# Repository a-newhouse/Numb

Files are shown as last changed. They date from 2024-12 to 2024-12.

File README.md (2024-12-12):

# Disclaimer
This is my first attempt, with [Duality](https://github.com/a-newhouse/Duality), to make a fully functional keyboard from A to Z. 
# Schematic
To start with, I knew I wanted to use an RP2040 and per key LEDs. So I searched how to make an RP2040 board amd i found a book made by Raberry PI called the [Hardware design with RP2040: Using RP2040 microcontrollers to build boards and products](./Schematic_&_PCB/Hardware_Design_RP2040.pdf). This book contains alot of information on how to make a RP2040 development board.
# PCB
# 3D modeling
# BOM
# Assembly
# QMK Firmware

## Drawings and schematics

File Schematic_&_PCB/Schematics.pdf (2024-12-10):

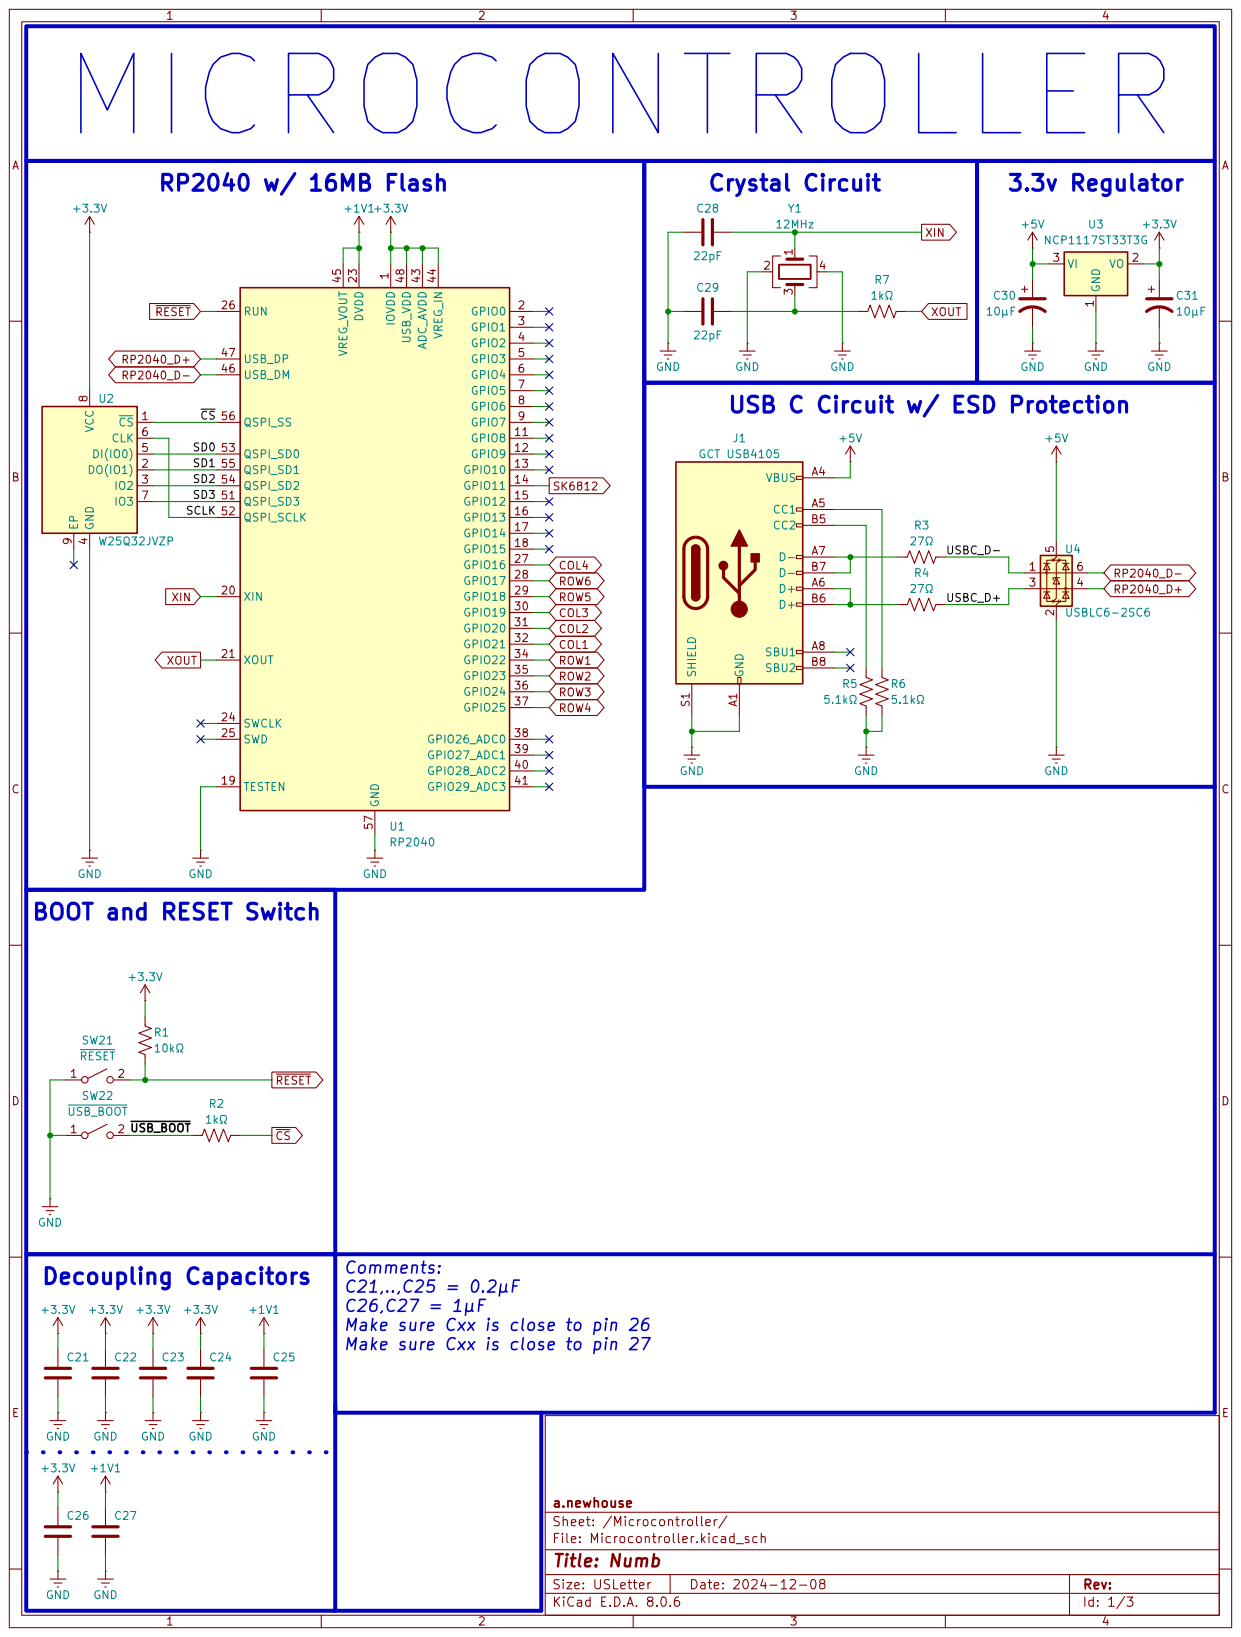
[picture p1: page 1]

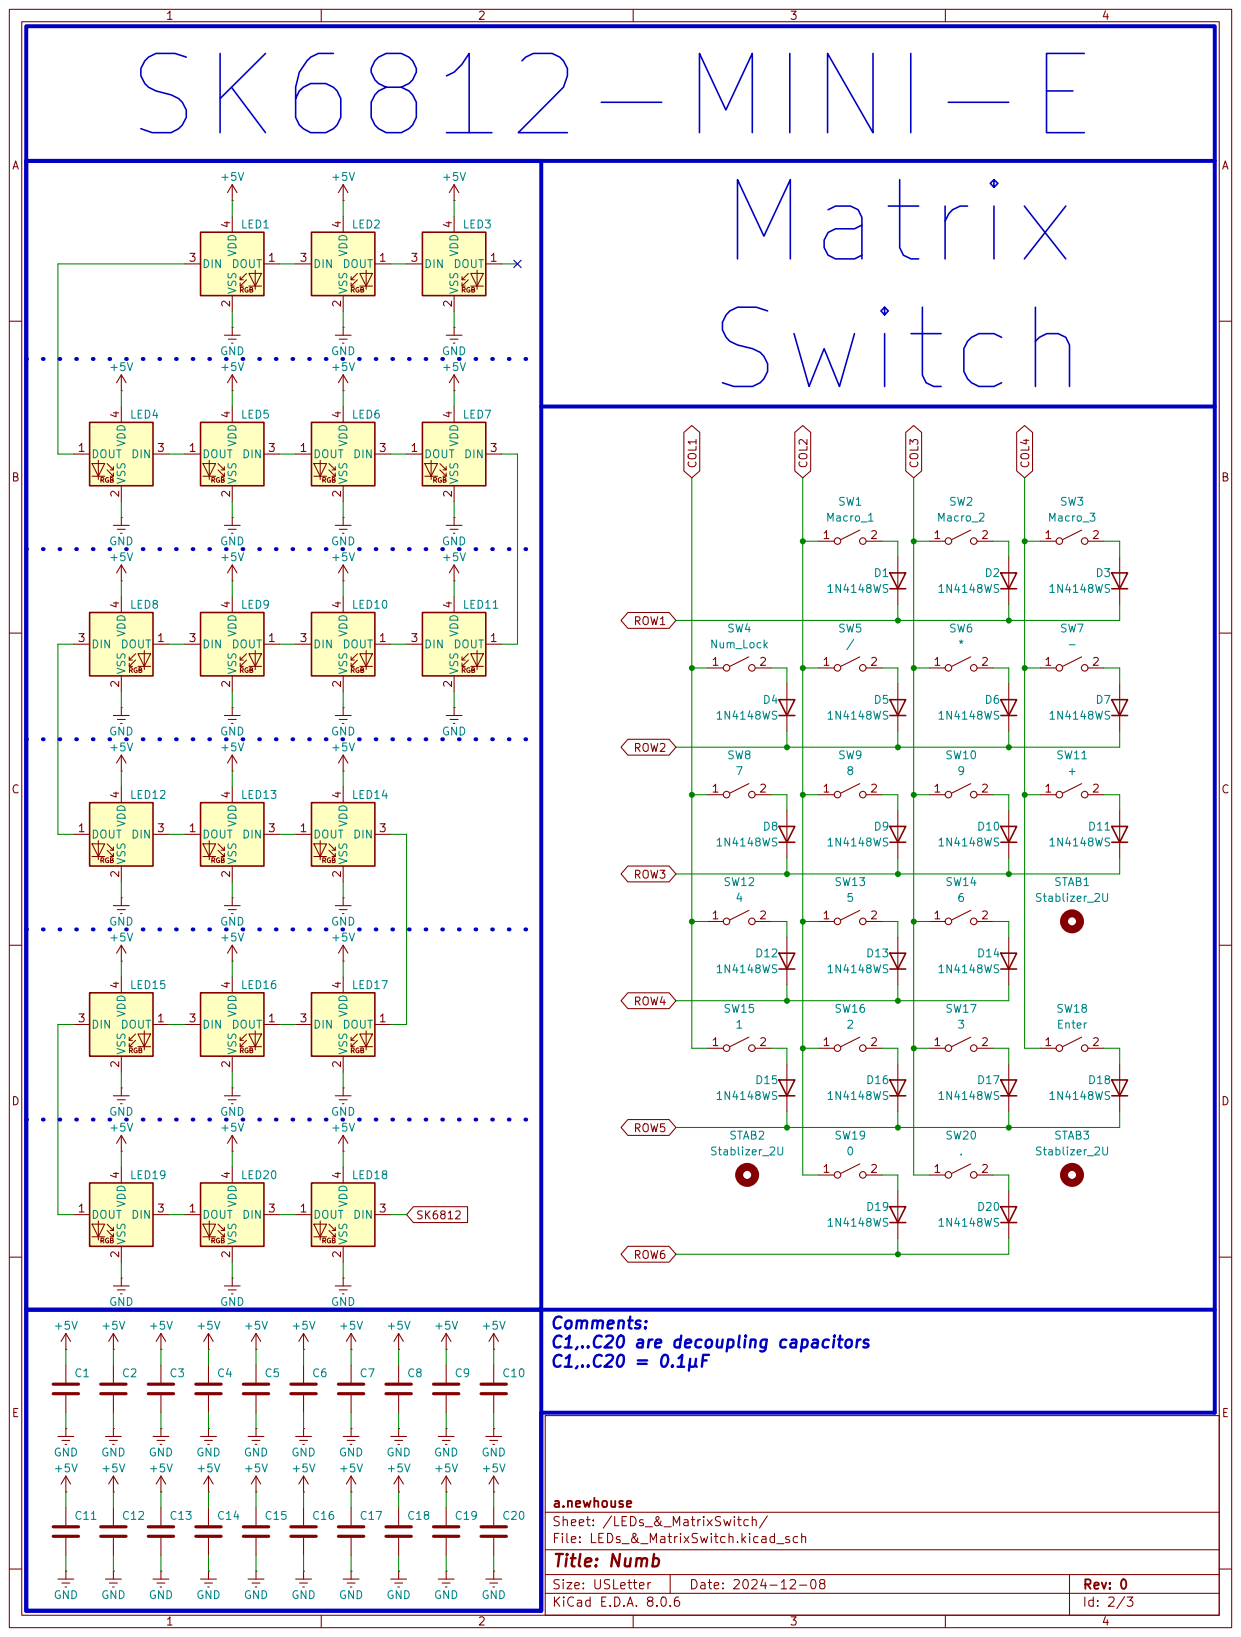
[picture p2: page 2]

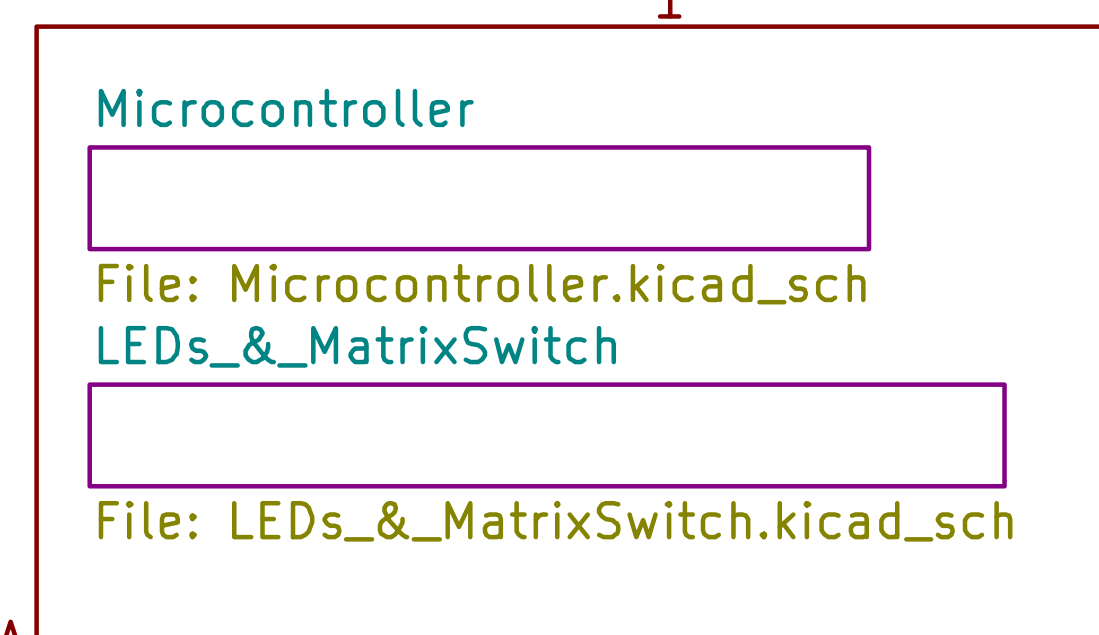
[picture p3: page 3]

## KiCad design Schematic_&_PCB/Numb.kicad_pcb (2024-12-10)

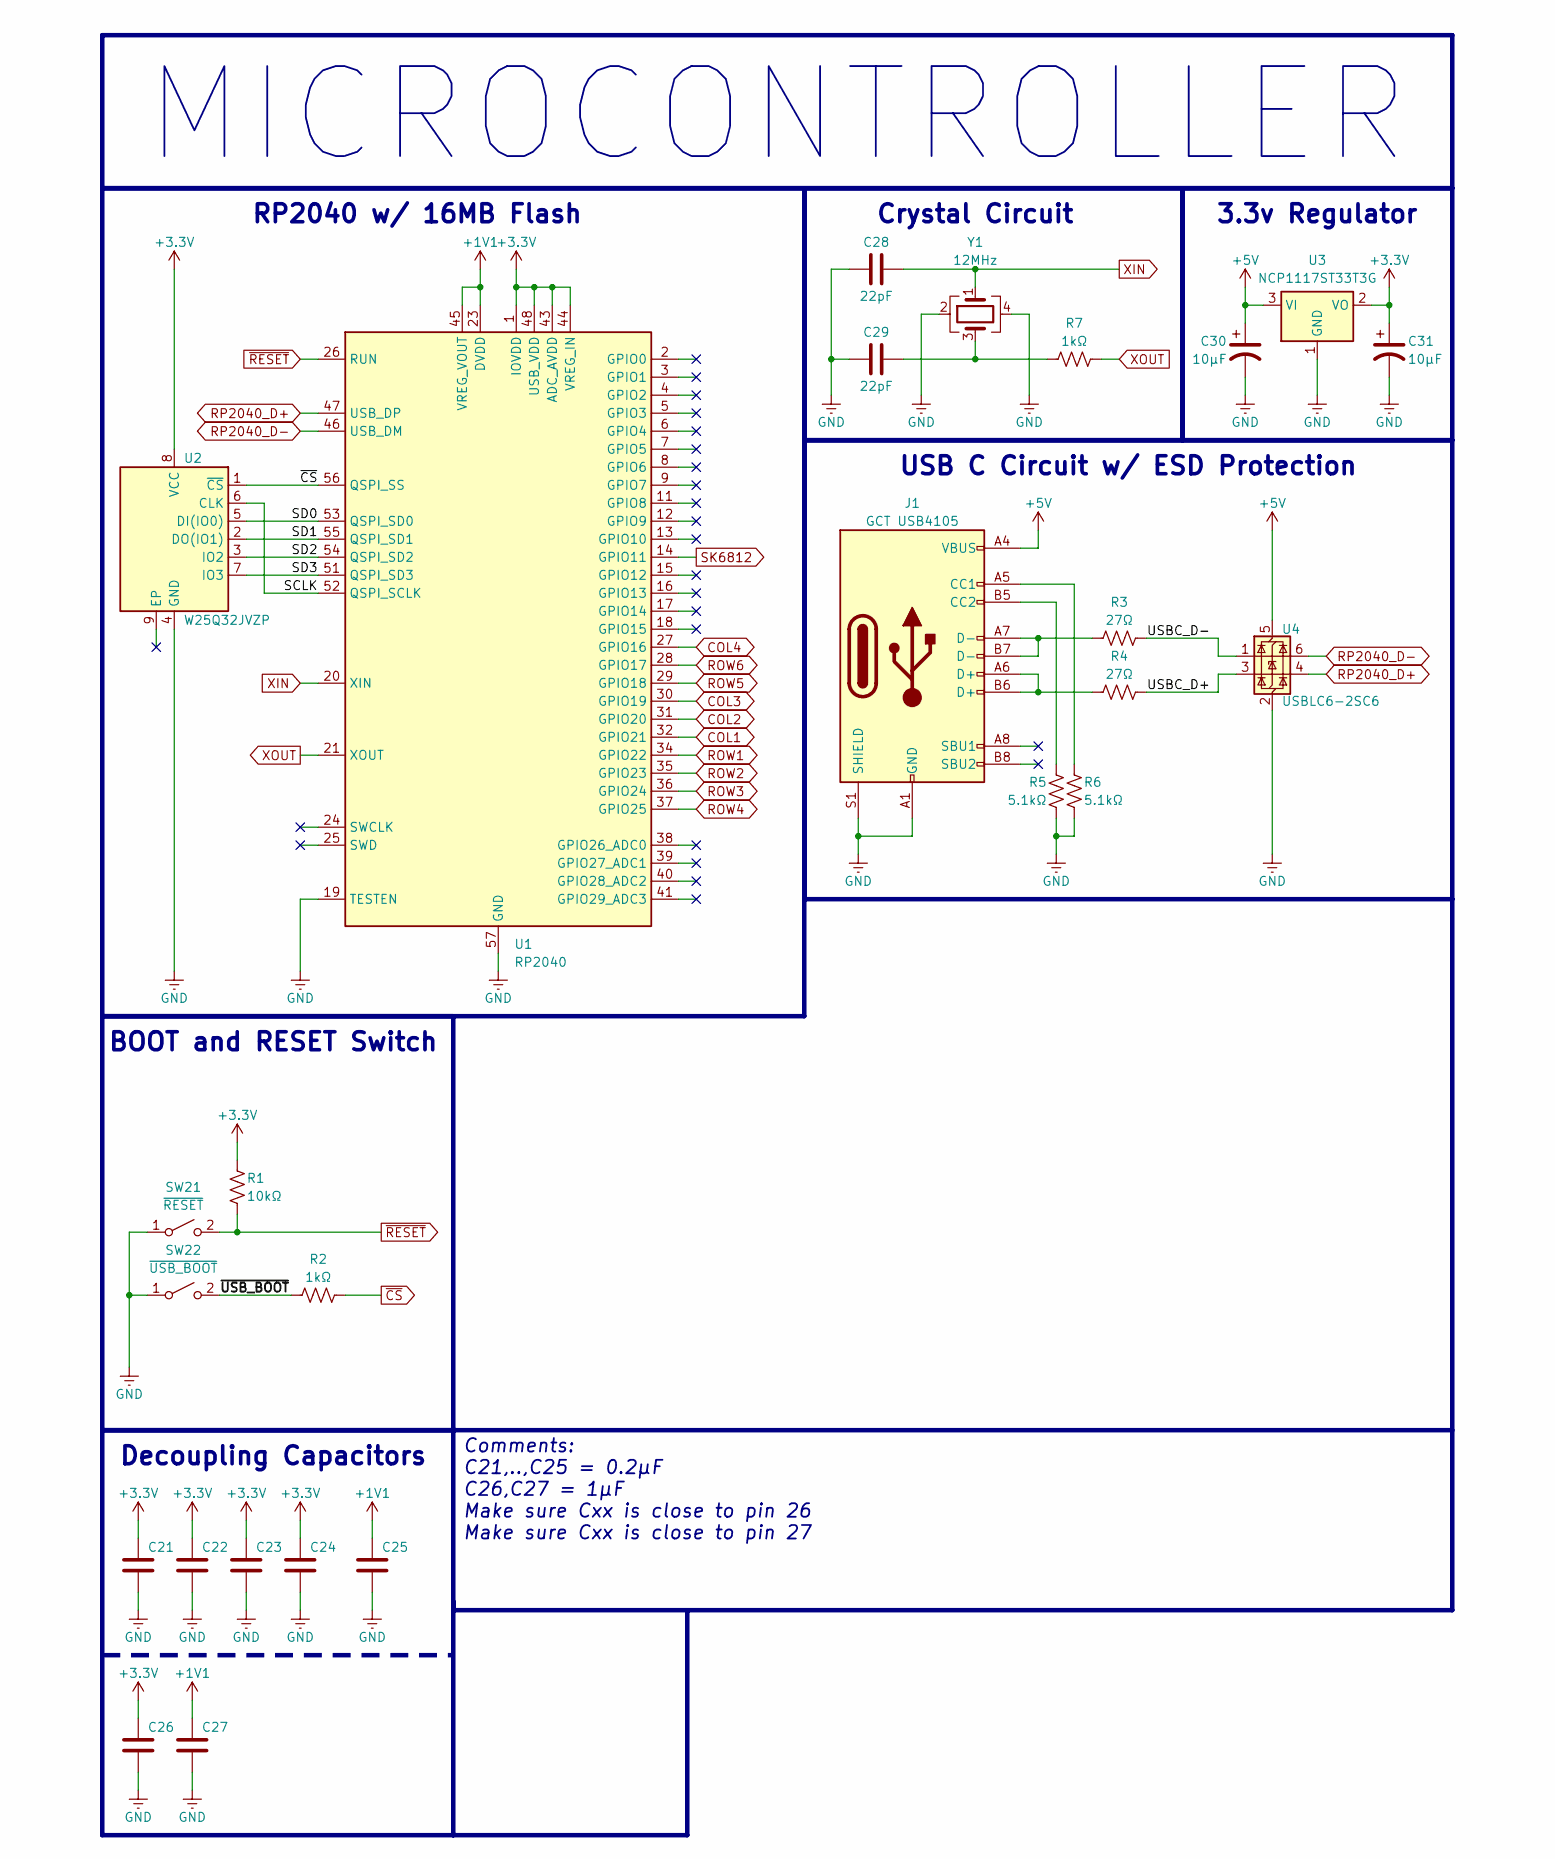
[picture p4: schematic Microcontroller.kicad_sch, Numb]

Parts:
C21, C22, C23, C24, C25: 0.2μF; C_0603_1608Metric
C26, C27: 1μF; C_0603_1608Metric
C28, C29: 22pF; C_0402_1005Metric
C30, C31: 10μF; CP_EIA-3216-10_Kemet-I
J1: GCT USB4105; USB_C_Receptacle_GCT_USB4105-xx-A_16P_TopMnt_Horizontal
R1: 10kΩ; R_0402_1005Metric
R2, R7: 1kΩ; R_0402_1005Metric
R3, R4: 27Ω; R_0603_1608Metric
R5, R6: 5.1kΩ; R_0402_1005Metric
SW21: ~{RESET}; SW_SPST_B3U-1000P-B
SW22: ~{USB_BOOT}; SW_SPST_B3U-1000P-B
U1: RP2040; QFN-56-1EP_7x7mm_P0.4mm_EP3.2x3.2mm
U2: W25Q32JVZP; WSON-8-1EP_6x5mm_P1.27mm_EP3.4x4.3mm
U3: NCP1117ST33T3G; SOT-223-3_TabPin2
U4: USBLC6-2SC6; SOT-23-6
Y1: 12MHz; Crystal_SMD_3225-4Pin_3.2x2.5mm

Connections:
+1V1: C25.1, C27.1, U1.23 (DVDD), U1.45 (VREG_VOUT), U1.50 (DVDD)
+3.3V: C21.1, C22.1, C23.1, C24.1, C26.1, C31.1, R1.1, U1.1 (IOVDD), U1.10 (IOVDD), U1.22 (IOVDD), U1.33 (IOVDD), U1.42 (IOVDD), U1.43 (ADC_AVDD), U1.44 (VREG_IN), U1.48 (USB_VDD), U1.49 (IOVDD), U2.8 (VCC), U3.2 (VO)
+5V: C30.1, J1.A4 (VBUS), J1.A9 (VBUS), J1.B4 (VBUS), J1.B9 (VBUS), U3.3 (VI), U4.5 (VBUS); also elsewhere on the board
/Microcontroller/SCLK: U1.52 (QSPI_SCLK), U2.6 (CLK)
/Microcontroller/SD0: U1.53 (QSPI_SD0), U2.5 (DI(IO0))
/Microcontroller/SD1: U1.55 (QSPI_SD1), U2.2 (DO(IO1))
/Microcontroller/SD2: U1.54 (QSPI_SD2), U2.3 (IO2)
/Microcontroller/SD3: U1.51 (QSPI_SD3), U2.7 (IO3)
/Microcontroller/USBC_D+: R4.2, U4.3 (I/O2)
/Microcontroller/USBC_D-: R3.2, U4.1 (I/O1)
/Microcontroller/~USB_BOOT: R2.1, SW22.2 (B)
COL1: U1.32 (GPIO21); also elsewhere on the board
COL2: U1.31 (GPIO20); also elsewhere on the board
COL3: U1.30 (GPIO19); also elsewhere on the board
COL4: U1.27 (GPIO16); also elsewhere on the board
GND: C21.2, C22.2, C23.2, C24.2, C25.2, C26.2, C27.2, C28.1, C29.1, C30.2, C31.2, J1.A1 (GND), J1.A12 (GND), J1.B1 (GND), J1.B12 (GND), J1.S1 (SHIELD), R5.2, R6.2, SW21.1 (A), SW22.1 (A), U1.19 (TESTEN), U1.57 (GND), U2.4 (GND), U3.1 (GND), U4.2 (GND), Y1.2, Y1.4; also elsewhere on the board
unnamed: C29.2, R7.1, Y1.3
unnamed: J1.A5 (CC1), R6.1
unnamed: J1.B5 (CC2), R5.1
unnamed: J1.A6 (D+), J1.B6 (D+), R4.1
unnamed: J1.A7 (D-), J1.B7 (D-), R3.1
ROW1: U1.34 (GPIO22); also elsewhere on the board
ROW2: U1.35 (GPIO23); also elsewhere on the board
ROW3: U1.36 (GPIO24); also elsewhere on the board
ROW4: U1.37 (GPIO25); also elsewhere on the board
ROW5: U1.29 (GPIO18); also elsewhere on the board
ROW6: U1.28 (GPIO17); also elsewhere on the board
RP2040_D+: U1.47 (USB_DP), U4.4 (I/O2)
RP2040_D-: U1.46 (USB_DM), U4.6 (I/O1)
SK6812: U1.14 (GPIO11); also elsewhere on the board
XIN: C28.2, U1.20 (XIN), Y1.1
XOUT: R7.2, U1.21 (XOUT)
~CS: R2.2, U1.56 (QSPI_SS), U2.1 (~CS)
~RESET: R1.2, SW21.2 (B), U1.26 (RUN)

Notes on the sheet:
Crystal Circuit
RP2040 w/ 16MB Flash
3.3v Regulator
Decoupling Capacitors
MICROCONTROLLER
USB C Circuit w/ ESD Protection
Comments: C21,..,C25 = 0.2μF C26,C27 = 1μF Make sure Cxx is close to pin 26 Make sure Cxx is close to pin 27
BOOT and RESET Switch

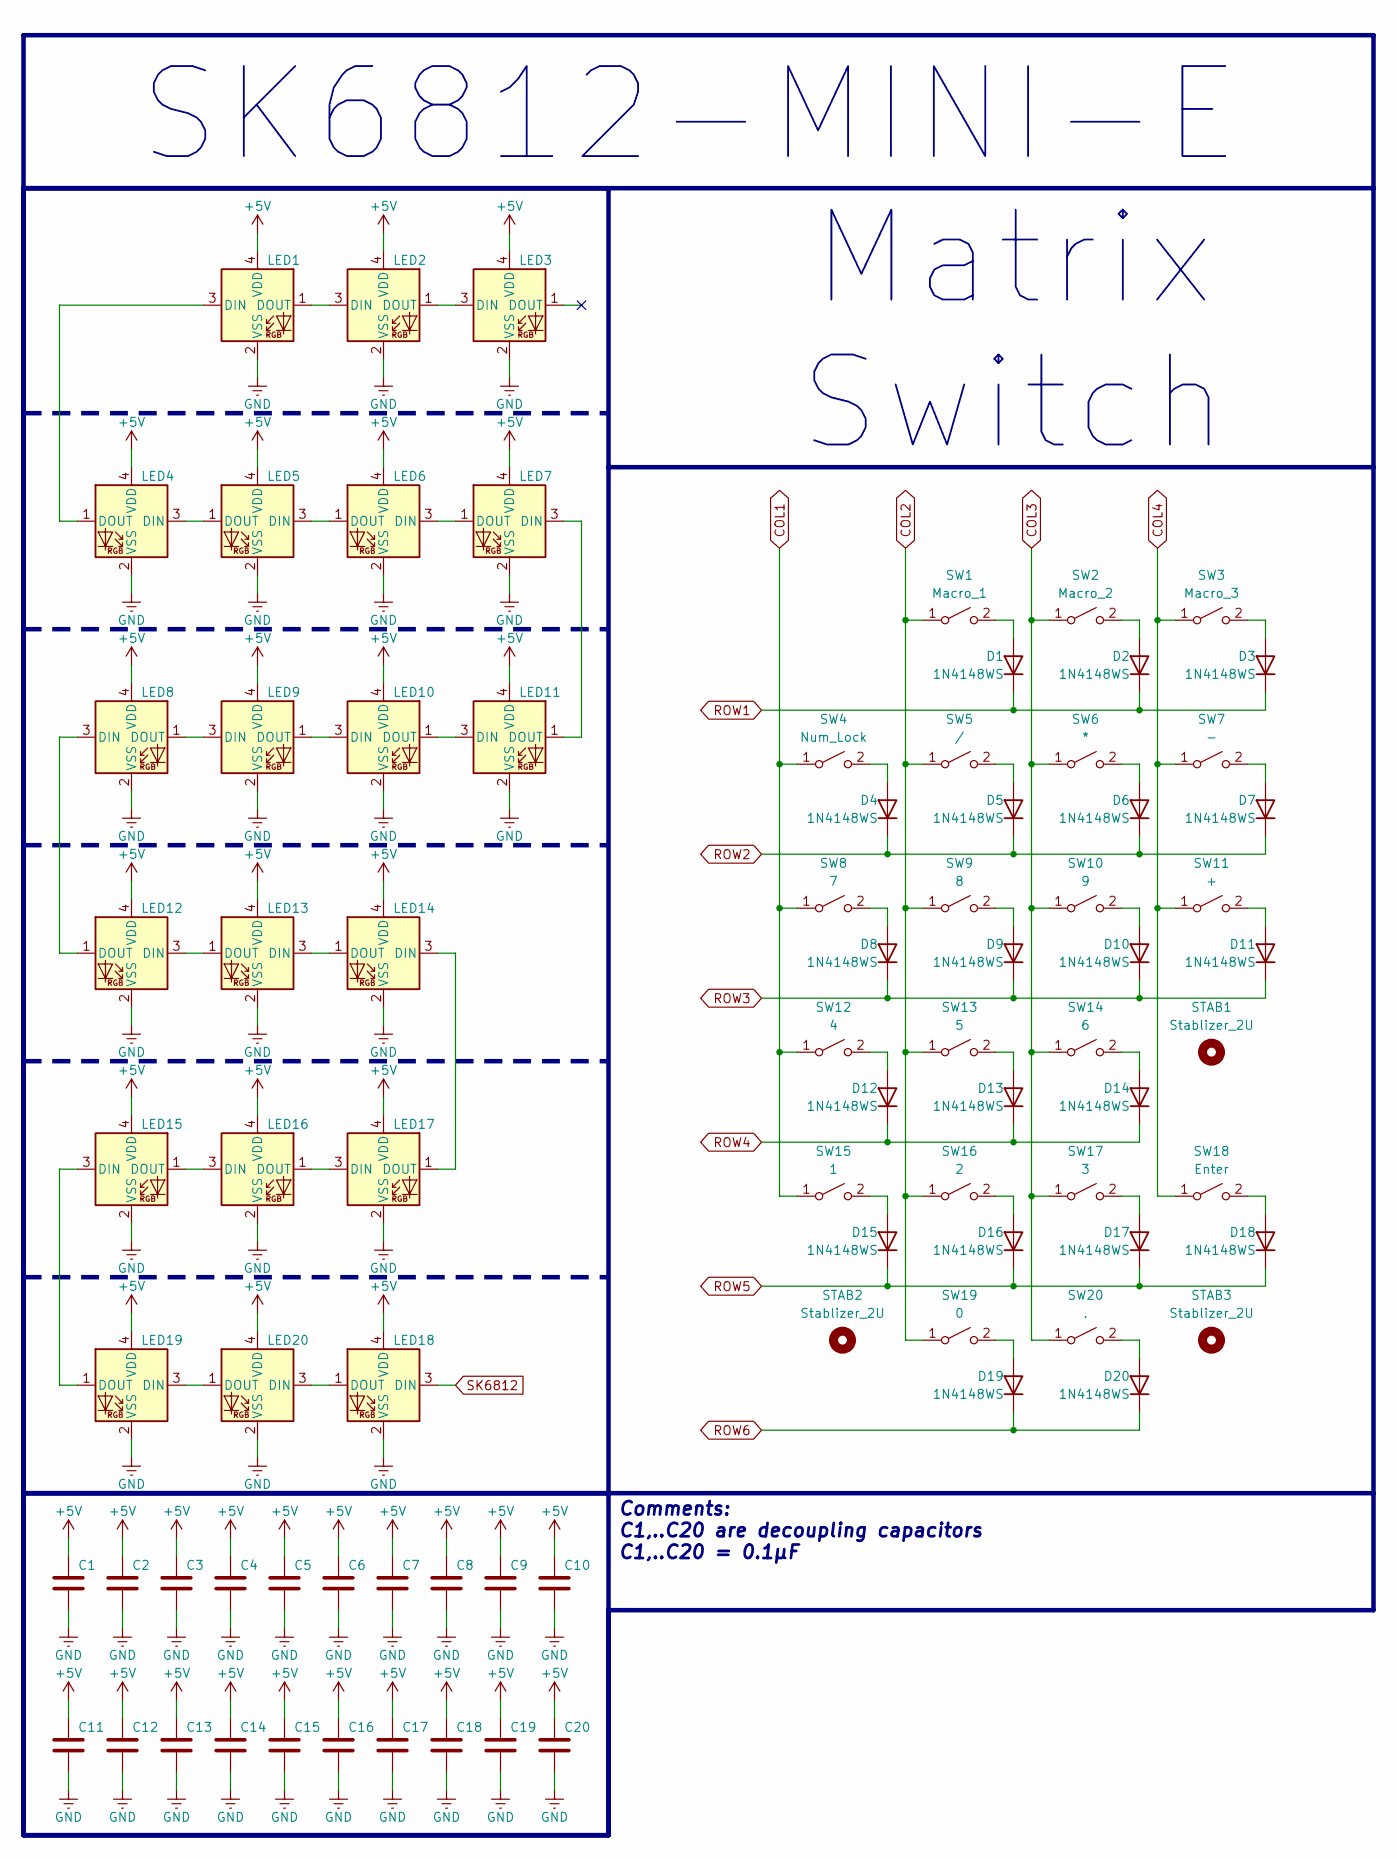
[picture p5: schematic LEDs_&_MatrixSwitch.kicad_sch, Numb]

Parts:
C1, C2, C3, C4, C5, C6, C7, C8, C9, C10, C11, C12, C13, C14, C15, C16, C17, C18, C19, C20: 0.1μF; C_0603_1608Metric
D1, D2, D3, D4, D5, D6, D7, D8, D9, D10, D11, D12, D13, D14, D15, D16, D17, D18, D19, D20: 1N4148WS; D_SOD-323
LED1, LED2, LED3, LED8, LED9, LED10, LED11, LED15, LED16, LED17: SK6812MINI-E; SK6812_MINI-E_REV
LED4, LED5, LED6, LED7, LED12, LED13, LED14, LED18, LED19, LED20: SK6812MINI-E; SK6812_MINI-E
STAB1, STAB2, STAB3: Stablizer_2U; Stabilizer_Cherry_MX_2.00u
SW1: Macro_1; SW_Hotswap_Kailh_MX_Plated_1.00u
SW2: Macro_2; SW_Hotswap_Kailh_MX_Plated_1.00u
SW3: Macro_3; SW_Hotswap_Kailh_MX_Plated_1.00u
SW4: Num_Lock; SW_Hotswap_Kailh_MX_Plated_1.00u
SW5: /; SW_Hotswap_Kailh_MX_Plated_1.00u
SW6: *; SW_Hotswap_Kailh_MX_Plated_1.00u
SW7: -; SW_Hotswap_Kailh_MX_Plated_1.00u
SW8: 7; SW_Hotswap_Kailh_MX_Plated_1.00u
SW9: 8; SW_Hotswap_Kailh_MX_Plated_1.00u
SW10: 9; SW_Hotswap_Kailh_MX_Plated_1.00u
SW11: +; SW_Hotswap_Kailh_MX_Plated_2.00u_90deg
SW12: 4; SW_Hotswap_Kailh_MX_Plated_1.00u
SW13: 5; SW_Hotswap_Kailh_MX_Plated_1.00u
SW14: 6; SW_Hotswap_Kailh_MX_Plated_1.00u
SW15: 1; SW_Hotswap_Kailh_MX_Plated_1.00u
SW16: 2; SW_Hotswap_Kailh_MX_Plated_1.00u
SW17: 3; SW_Hotswap_Kailh_MX_Plated_1.00u
SW18: Enter; SW_Hotswap_Kailh_MX_Plated_2.00u_90deg
SW19: 0; SW_Hotswap_Kailh_MX_Plated_2.00u
SW20: .; SW_Hotswap_Kailh_MX_Plated_1.00u

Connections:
+5V: C1.1, C2.1, C3.1, C4.1, C5.1, C6.1, C7.1, C8.1, C9.1, C10.1, C11.1, C12.1, C13.1, C14.1, C15.1, C16.1, C17.1, C18.1, C19.1, C20.1, LED1.4 (VDD), LED2.4 (VDD), LED3.4 (VDD), LED4.4 (VDD), LED5.4 (VDD), LED6.4 (VDD), LED7.4 (VDD), LED8.4 (VDD), LED9.4 (VDD), LED10.4 (VDD), LED11.4 (VDD), LED12.4 (VDD), LED13.4 (VDD), LED14.4 (VDD), LED15.4 (VDD), LED16.4 (VDD), LED17.4 (VDD), LED18.4 (VDD), LED19.4 (VDD), LED20.4 (VDD); also elsewhere on the board
COL1: SW4.1 (A), SW8.1 (A), SW12.1 (A), SW15.1 (A); also elsewhere on the board
COL2: SW1.1 (A), SW5.1 (A), SW9.1 (A), SW13.1 (A), SW16.1 (A), SW19.1 (A); also elsewhere on the board
COL3: SW2.1 (A), SW6.1 (A), SW10.1 (A), SW14.1 (A), SW17.1 (A), SW20.1 (A); also elsewhere on the board
COL4: SW3.1 (A), SW7.1 (A), SW11.1 (A), SW18.1 (A); also elsewhere on the board
GND: C1.2, C2.2, C3.2, C4.2, C5.2, C6.2, C7.2, C8.2, C9.2, C10.2, C11.2, C12.2, C13.2, C14.2, C15.2, C16.2, C17.2, C18.2, C19.2, C20.2, LED1.2 (VSS), LED2.2 (VSS), LED3.2 (VSS), LED4.2 (VSS), LED5.2 (VSS), LED6.2 (VSS), LED7.2 (VSS), LED8.2 (VSS), LED9.2 (VSS), LED10.2 (VSS), LED11.2 (VSS), LED12.2 (VSS), LED13.2 (VSS), LED14.2 (VSS), LED15.2 (VSS), LED16.2 (VSS), LED17.2 (VSS), LED18.2 (VSS), LED19.2 (VSS), LED20.2 (VSS); also elsewhere on the board
unnamed: D1.2 (A), SW1.2 (B)
unnamed: D2.2 (A), SW2.2 (B)
unnamed: D3.2 (A), SW3.2 (B)
unnamed: D4.2 (A), SW4.2 (B)
unnamed: D5.2 (A), SW5.2 (B)
unnamed: D6.2 (A), SW6.2 (B)
unnamed: D7.2 (A), SW7.2 (B)
unnamed: D8.2 (A), SW8.2 (B)
unnamed: D9.2 (A), SW9.2 (B)
unnamed: D10.2 (A), SW10.2 (B)
unnamed: D11.2 (A), SW11.2 (B)
unnamed: D12.2 (A), SW12.2 (B)
unnamed: D13.2 (A), SW13.2 (B)
unnamed: D14.2 (A), SW14.2 (B)
unnamed: D15.2 (A), SW15.2 (B)
unnamed: D16.2 (A), SW16.2 (B)
unnamed: D17.2 (A), SW17.2 (B)
unnamed: D18.2 (A), SW18.2 (B)
unnamed: D19.2 (A), SW19.2 (B)
unnamed: D20.2 (A), SW20.2 (B)
unnamed: LED1.3 (DIN), LED4.1 (DOUT)
unnamed: LED1.1 (DOUT), LED2.3 (DIN)
unnamed: LED2.1 (DOUT), LED3.3 (DIN)
unnamed: LED4.3 (DIN), LED5.1 (DOUT)
unnamed: LED5.3 (DIN), LED6.1 (DOUT)
unnamed: LED6.3 (DIN), LED7.1 (DOUT)
unnamed: LED8.1 (DOUT), LED9.3 (DIN)
unnamed: LED9.1 (DOUT), LED10.3 (DIN)
unnamed: LED10.1 (DOUT), LED11.3 (DIN)
unnamed: LED7.3 (DIN), LED11.1 (DOUT)
unnamed: LED12.3 (DIN), LED13.1 (DOUT)
unnamed: LED8.3 (DIN), LED12.1 (DOUT)
unnamed: LED13.3 (DIN), LED14.1 (DOUT)
unnamed: LED14.3 (DIN), LED17.1 (DOUT)
unnamed: LED15.3 (DIN), LED19.1 (DOUT)
unnamed: LED15.1 (DOUT), LED16.3 (DIN)
unnamed: LED16.1 (DOUT), LED17.3 (DIN)
unnamed: LED18.1 (DOUT), LED20.3 (DIN)
unnamed: LED19.3 (DIN), LED20.1 (DOUT)
ROW1: D1.1 (K), D2.1 (K), D3.1 (K); also elsewhere on the board
ROW2: D4.1 (K), D5.1 (K), D6.1 (K), D7.1 (K); also elsewhere on the board
ROW3: D8.1 (K), D9.1 (K), D10.1 (K), D11.1 (K); also elsewhere on the board
ROW4: D12.1 (K), D13.1 (K), D14.1 (K); also elsewhere on the board
ROW5: D15.1 (K), D16.1 (K), D17.1 (K), D18.1 (K); also elsewhere on the board
ROW6: D19.1 (K), D20.1 (K); also elsewhere on the board
SK6812: LED18.3 (DIN); also elsewhere on the board

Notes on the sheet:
Matrix Switch
Comments: C1,..C20 are decoupling capacitors C1,..C20 = 0.1μF
SK6812-MINI-E

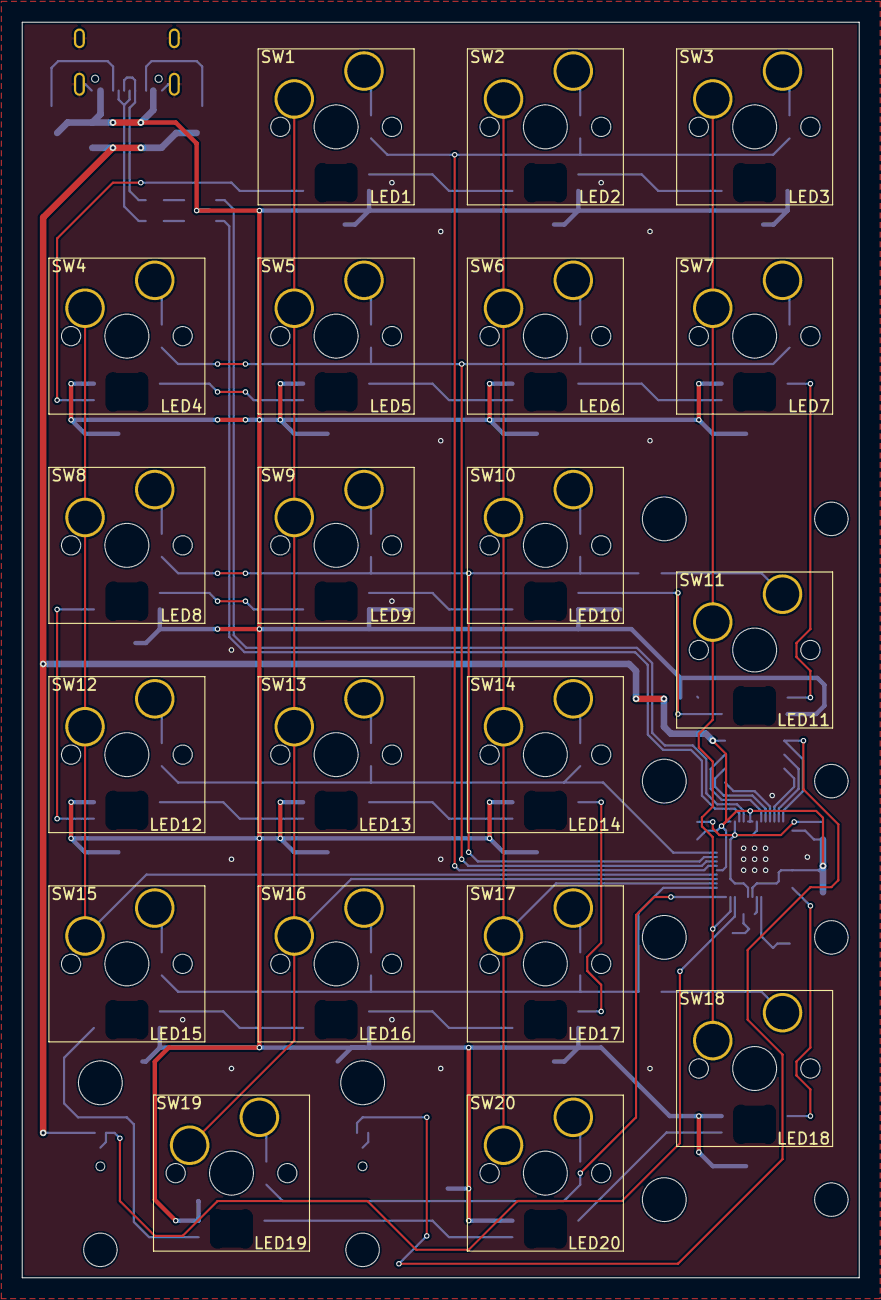
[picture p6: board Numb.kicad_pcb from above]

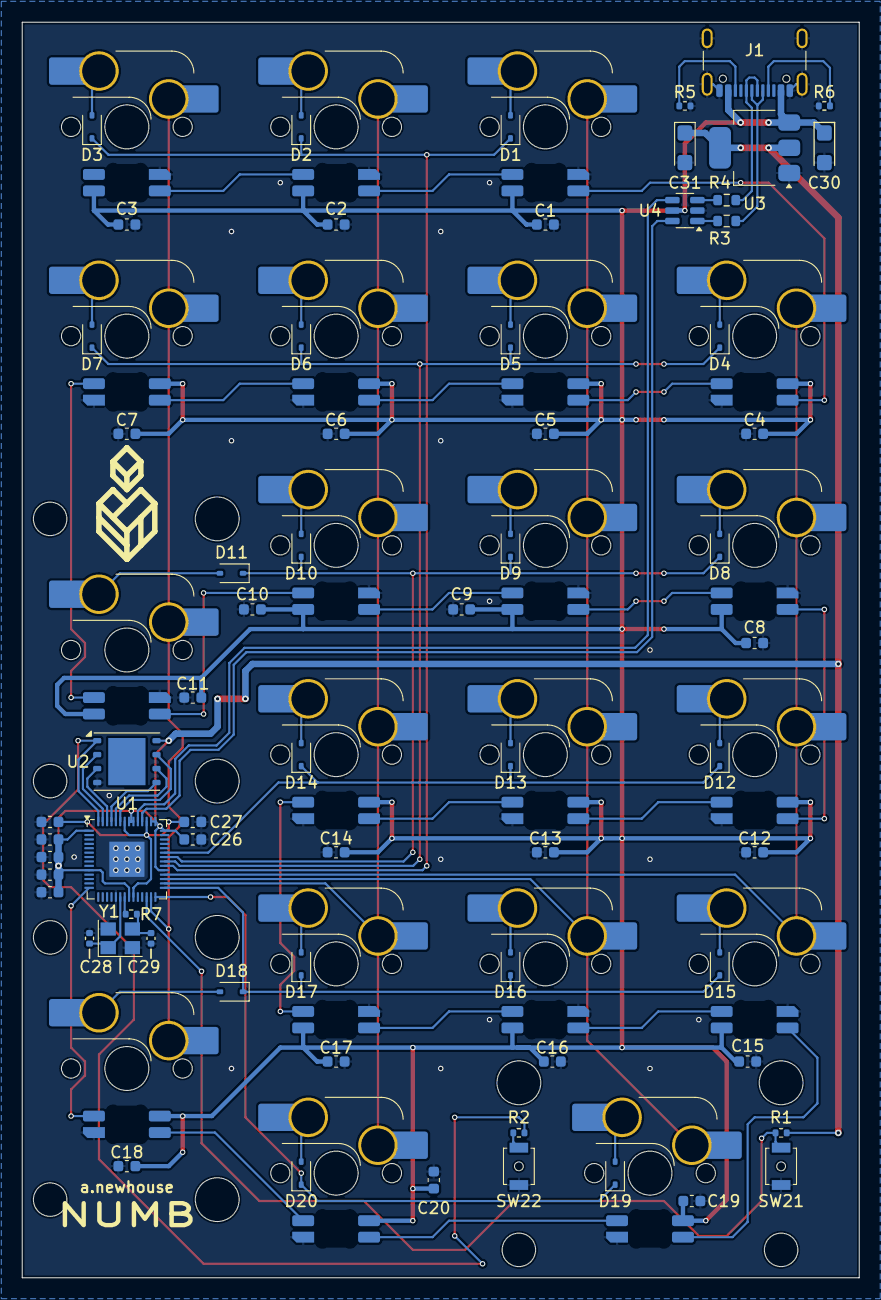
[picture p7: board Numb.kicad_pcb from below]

Board: 2 copper layers, 76.2 x 114.3 mm, 109 parts (106 on the bottom side), 73 nets.

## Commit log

2024-12-10 Added Kicad Files
    [LEDs_&_MatrixSwitch.kicad_sch, Microcontroller.kicad_sch, Numb.kicad_pcb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]
2024-12-16 changed the mcu
    [Microcontroller.kicad_sch]
